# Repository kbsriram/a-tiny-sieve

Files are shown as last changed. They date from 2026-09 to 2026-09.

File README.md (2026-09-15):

# A tiny sieve

Software and hardware for [A Tiny Sieve: Lehmer's math machine in ATtinys](https://hackaday.io/project/206556-a-tiny-sieve-lehmers-math-machine-in-attinys).

A number sieve rejects candidate integers that cannot solve a quadratic
equation, using arithmetic modulo small primes. One ATtiny412 holds one
modulus. They share one open-drain line: any chip that rejects pulls it low, so
the line stays high only when no chip rejected. A Raspberry Pi Pico clocks them
and checks whatever survives.

# Software

One directory per build log, each with its own README:

- [code/01](code/01) — [The sound of sieving](https://hackaday.io/project/206556-a-tiny-sieve-lehmers-math-machine-in-attinys/log/250443-the-sound-of-sieving).
  Three moduli hardcoded, stepped by a button, a buzzer on the shared line.
  Solves `y^2 - 2x^2 = 4001`.
- [code/02](code/02) — [Sieving versus checking](https://hackaday.io/project/206556-a-tiny-sieve-lehmers-math-machine-in-attinys/log/250562-sieving-versus-checking).
  Rings loaded over I2C, clocked at 50 kHz by the Pico's PIO, survivors tested
  on the Pico. Factors 5,283,065,753,709,209.
- [code/04](code/04) — [Qualify the moduli](https://hackaday.io/project/206556-a-tiny-sieve-lehmers-math-machine-in-attinys/log/250711-qualify-the-moduli).
  Testing cards before they ship. Flash a diagnostic image, check the header
  pins from a Pico, then flash the real firmware.
- [code/05](code/05) — Thirty cards on a stripboard backplane. Self-checks over
  I2C before a run, and the REQ-to-VOTE timing measured with all thirty fitted.

Each build pairs an `avr/` half (ATtiny412 firmware in C, avr-gcc) with an
`rpi/` half (Pico host code). The Pico runtime differs per build — build 01 is
CircuitPython, builds 02, 04 and 05 are MicroPython — so check the build's README
before copying files to a board.

# Hardware

- [hardware/modulus](hardware/modulus) is an ATtiny412 on a card that plugs into the sieve backplane. Gerbers, Altium source files and JLCPCB BOM and pick-and-place are available.

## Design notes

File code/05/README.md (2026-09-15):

# 05 - Board bring-up, self-tests

[Build log](https://hackaday.io/project/206556-a-tiny-sieve-lehmers-math-machine-in-attinys/log/250782-the-modulus-chorus-rehearses)

Thirty ATtiny412 cards in a stripboard backplane, checked before a run. The
card firmware gains a CRC-8 checked I2C protocol with a readable status, and a
hand-written interrupt handler that drives VOTE in its first instruction.

## Signals

- **REQ** — Pico output (GP17) to every card (PA6). Each rising edge makes
  every armed card drive VOTE from its ring and advance its phase by one.
- **VOTE** — one wire shared by all thirty cards (PA3) and read by the Pico
  (GP21). No pull-up resistor is fitted: the line is held high by the cards'
  internal pull-ups in parallel, about 1.2 kOhm.
- **I2C** — Pico (GP18 SDA, GP19 SCL) to every card (PA1, PA2) and to an
  SSD1306, at 100 kHz. Cards take no I2C traffic while armed, so REQ is held
  low for every transaction.
- **LED** — PA7 on each card, lit whenever that card is driving VOTE low.

Measured with all thirty cards fitted: 947 ns from a REQ rising edge to VOTE
low, and 1.684 us from the same edge to VOTE settled high.

## ATtiny412 firmware — `avr/`

`src/hal/hal_gpio.c` holds the REQ handler: six assembly instructions with four
registers reserved across the build, and the next phase's port-direction byte
precomputed, so the first instruction executed drives VOTE. `src/task/task_cmd.c`
decodes five commands, each ending in a CRC-8 PEC, and answers every one with a
response code the host reads back. `src/task/task_sieve.c` holds the ring.

Build and flash over serial UPDI, once per card with a distinct I2C address:

    cd avr/src
    make clean flash ADDR=0x10

Set `BASE` and `PORT` for your toolchain and UPDI adapter. Host tests of
`task_cmd.c` and `task_sieve.c` against vectors generated by
`avr/test/ref/model.py`, no hardware needed: `cd avr/test/host && make test`.

## Flashing a batch — `jig/`

`flash_batch.py` runs on the PC and walks a tray of cards one at a time: build
both images, flash the log 4 diagnostic image, run its electrical checks, flash
the log 5 image for the next free address, then check over I2C that the card
answers there and steps its ring. A card that fails any step does not consume
an address.

    python3 jig/flash_batch.py                # batch loop over 30 addresses
    python3 jig/flash_batch.py --verify 0x17  # functional check only

## Pico host — `rpi/` (MicroPython)

`card.py` is one card, `bank.py` all thirty plus the shared REQ and VOTE lines.
`selftest.py` runs the five pre-run checks — roll call, REQ bridge, idle VOTE,
LED walk, and one card at a time against its own ring. `timing.py` loads one
common ring and drives REQ from a hardware PWM, so the scope sees a steady
pattern. `panel.py` drives the OLED, and does nothing if none is fitted.

    cd rpi
    mpremote mount . exec "import selftest; selftest.main(30)"

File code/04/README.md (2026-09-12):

# Card test jig

Tests one ATtiny412 modulus card before it gets the shipping firmware.
Card schematic: [hardware/modulus](../../hardware/modulus).

`test_and_flash.sh` flashes a diagnostic image over UPDI (a UPDI
Friend on H1 pin 6, PA0), then runs the Pico checks. `PORT=` sets the UPDI
serial port; `--batch` loops over a tray of cards.

Diagnostic image: PA6, PA1, PA2, PA3 are inputs with pull-ups; PA7 is a
push-pull output toggling every 1 s.

Checks, in order:

1. All five pins read high. Finds shorts to GND.
2. Drive each of PA6, PA1, PA2, PA3 low in turn; the rest stay high.
   Finds bridges. A pin that will not read low is shorted to VCC.
3. Release all; all read high. Finds opens.
4. Hold pin 3 low for 3 s; no pin follows PA7. Finds a closed JP1
   and any bridge to PA7.

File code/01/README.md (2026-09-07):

# 01 — the sound of sieving

Log: [The sound of sieving](https://hackaday.io/project/206556-a-tiny-sieve-lehmers-math-machine-in-attinys/log/250443-the-sound-of-sieving)

Sieves `y^2 - 2x^2 = 4001`. Three ATtiny412s each hold one modulus, a push
button steps all of them together, and a piezo buzzer sounds on every rejection.

## Wiring

One switch goes to PA1 on every chip, with the internal pull-up on and the other
side to ground, so a press advances every chip's counter by one. PA2 on every
chip is tied to one line, pulled high, with the buzzer across it: a chip that
rejects drives its pin to 0V for about 62 ms, a chip that accepts leaves the pin
as a high-impedance input.

## ATtiny412 firmware — `avr/`

`src/task/task_check.c` holds the accept/reject pattern as a `bool` array, one
entry per residue. Patterns for mod 3, 5, 7 and 11 are all in the file, with one
active and the rest commented out, so you edit and reflash per chip.
`src/task/task_button.c` debounces the press over 3 ticks of the 15.625 ms RTC;
`src/task/task_beep.c` holds the buzzer down for 4 ticks; `src/hal/hal_gpio.c`
drives PA2 with `PORTA.DIRSET`/`DIRCLR`.

    cd avr/src
    make flash            # serial UPDI; set BASE and PORT in the Makefile
    cd ../test/host && make test   # task unit tests, no hardware needed

## Pico — `rpi/` (CircuitPython)

Counts and displays how many candidates have been stepped through. Copy
`code.py` and `lib/` to the CIRCUITPY drive. `lib/button.py` debounces the
switch with a 47 ms settle window; `lib/count_display.py` drives a 128x64
SSD1306 OLED over I2C.

`diag.py` prints how long the switch stayed at each level. Copy it over
`code.py` to measure the contact bounce that made the count jump by more than
one per press.

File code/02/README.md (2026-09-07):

# 02 — sieving versus checking

Log: [Sieving versus checking](https://hackaday.io/project/206556-a-tiny-sieve-lehmers-math-machine-in-attinys/log/250562-sieving-versus-checking)

Factors 5,283,065,753,709,209 by searching for `a^2 + 7*(4k)^2 = N`. Three
ATtiny412s reject candidate values of `k`; a Pico steps them and tests what
survives for a perfect square.

## Signals

- **REQ** — Pico output (GP14) to every ATtiny (PA6). Each rising edge makes
  every chip read one bit of its ring and advance its counter by one.
- **VOTE** — one wire shared by all three chips (PA7) and read by the Pico
  (GP15). A chip that rejects drives it low; a chip that accepts leaves the pin
  as a high-impedance input. So VOTE is high only if no chip rejected.
- **I2C** — Pico (GP16 SDA, GP17 SCL) to each chip (PA1, PA2), used before the
  run to load each chip's modulus and ring.

A chip's *ring* is its modulus `p` plus 16 bytes = 128 bits, one bit per
residue: bit `r` is 1 if `N - 7*(4r)^2` is a quadratic residue mod `p`, meaning
candidates with `k = r mod p` can still be solutions. 128 bits caps the modulus
at 128.

## ATtiny412 firmware — `avr/`

`src/task/task_sieve.c` is the whole rejecter: modulus, ring, phase counter, and
three I2C commands — `0x01` set ring, `0x02` reset and disarm, `0x03` arm.
`src/hal/hal_gpio.c` does the open-drain VOTE with `PORTA.DIRSET`/`DIRCLR`.
`main.c` never sleeps while armed, because waking from sleep costs microseconds
that would push the REQ-to-VOTE delay past the 20 us step period.

Build and flash over serial UPDI, once per chip with a distinct I2C address:

    cd avr/src
    make ADDR=0x20 flash
    make ADDR=0x21 flash
    make ADDR=0x22 flash

Set `BASE` and `PORT` in `src/Makefile` for your toolchain and UPDI adapter.
Host-side unit tests of `task_sieve.c` (no hardware needed): `cd avr/test/host
&& make test`.

## Pico host — `rpi/` (MicroPython)

`sieve_runner.py` holds the PIO program: it drives REQ at 50 kHz (10 us high,
10 us low), samples VOTE near the end of the low phase, and pushes a 64-bit
candidate index into the FIFO only when VOTE was high. `sieve.py` is the I2C
driver for one chip. `check_16.py` builds the rings from quadratic residues,
verifies the first 10,000 candidates against a Python oracle, then runs to
completion and recovers the factors with `gcd`.

Run anything with the directory mounted, no copying to flash:

    cd rpi
    mpremote mount . run check_16.py

## Tests

All four need the hardware attached, and are run the same way.

- `test_functional.py` — one chip, degenerate rings (all-accept, all-reject,
  alternating, single bit); the other chips left disarmed.
- `test_survivors.py` — arms 1, then 2, then 3 chips and re-checks survivors,
  confirming disarmed chips never pull VOTE low.
- `test_differential.py` — random rings across moduli up to 127, checking the
  ring wraps correctly at byte boundaries.
- `test_overflow.py` — the PIO's 64-bit candidate counter across 0xFFFFFFFF.

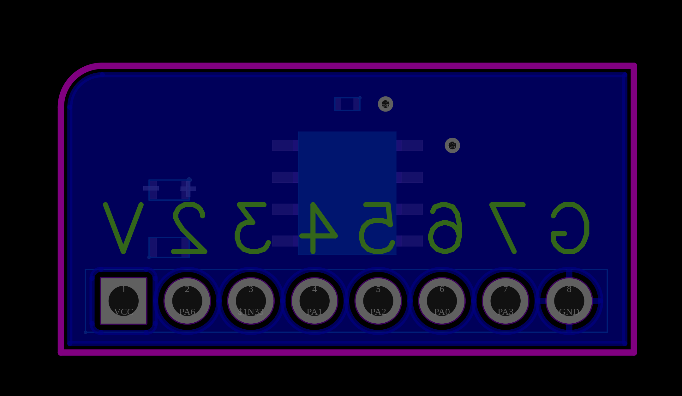
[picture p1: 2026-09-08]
hardware/modulus/pcb_back.png

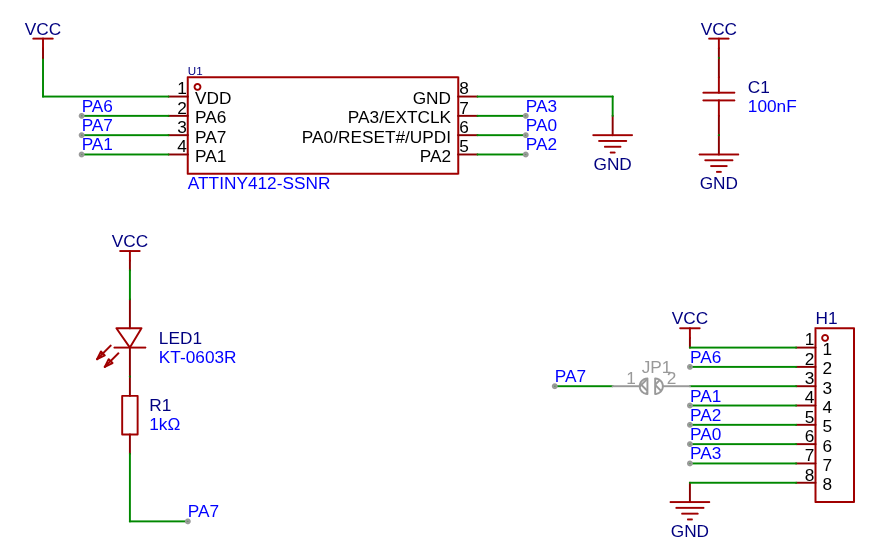
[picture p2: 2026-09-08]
hardware/modulus/schematic.png

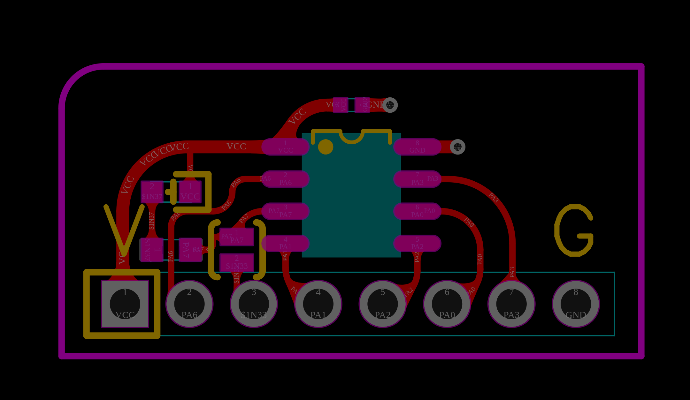
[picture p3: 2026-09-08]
hardware/modulus/pcb_front.png

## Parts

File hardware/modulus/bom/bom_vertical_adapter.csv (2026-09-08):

No. | Quantity | Comment | Designator | Footprint | Value | Manufacturer Part | Manufacturer | Supplier Part | Supplier
1 | 1 | 100nF | C1 | C0402 | 100nF | CL05B104KB54PNC | SAMSUNG(三星) | C307331 | LCSC
2 | 1 | HDR-F_2.54_1x8P | H1 | HDR-TH_8P-P2.54-V-F-1
3 | 1 | KT-0603R | LED1 | LED-SMD_L1.6-W0.8-R-RD |  | KT-0603R | KENTO | C2286 | LCSC
4 | 1 | 1kΩ | R1 | R0603 | 1kΩ | 0603WAF1001T5E | UNI-ROYAL(厚声) | C21190 | LCSC
5 | 1 | ATTINY412-SSNR | U1 | SOIC-8_L4.9-W3.9-P1.27-LS6.0-BL |  | ATTINY412-SSNR | MICROCHIP(美国微芯) | C1337190 | LCSC

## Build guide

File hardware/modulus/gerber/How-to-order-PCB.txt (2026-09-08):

How to Order PCB

Please refer to:
https://prodocs.easyeda.com/en/pcb/order-order-pcb/index.html

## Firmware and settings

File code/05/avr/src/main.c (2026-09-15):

#include <avr/interrupt.h>
#include <stdint.h>

#include "hal/hal_gpio.h"
#include "hal/hal_system.h"
#include "hal/hal_twi.h"
#include "task/task_cmd.h"

// Apply pin-level effects of the command task_cmd already decoded.
static void apply_command(void) {
  switch (task_cmd_accepted_op()) {
    case TASK_CMD_OP_SET_RING:
      // SET_RING disarms (clearing the LED); restore the LED state after.
      hal_gpio_disarm();
      hal_gpio_set_ring();
      hal_gpio_led(task_cmd_led());
      break;
    case TASK_CMD_OP_RESET:
      hal_gpio_disarm();
      break;
    case TASK_CMD_OP_ARM:
      hal_gpio_arm(task_cmd_accepted_phase());
      break;
    case TASK_CMD_OP_LED:
      hal_gpio_led(task_cmd_led());
      break;
    default:
      break;
  }
}

int main(void) {
  hal_system_init();
  // Pins first: VOTE and the LED stay high-impedance until a command or a REQ
  // edge changes them.
  hal_gpio_init();

  // Same address twice: task_cmd seeds every CRC with it, hal_twi matches it.
  task_cmd_init(I2C_ADDR);
  hal_twi_init(I2C_ADDR);

  sei();

  // Never sleeps, never disables interrupts: every REQ edge reaches the handler
  // in the cycle count hal_gpio.c guarantees.
  while (1) {
    if (hal_twi_take_command()) {
      apply_command();
    }
  }
}

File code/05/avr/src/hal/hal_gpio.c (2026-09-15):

#include "hal_gpio.h"

#include <avr/cpufunc.h>
#include <avr/interrupt.h>
#include <avr/io.h>

#include "task/task_sieve.h"

// DIR=1 drives low; OUT stays 0. 0x88 sinks VOTE and lights the LED.
#define VOTE_LOW_DIR (PIN3_bm | PIN7_bm)

// VPORTA.DIR value per phase. One spare entry so the ISR's pointer stays
// in-bounds after the last phase.
static uint8_t s_dir[TASK_SIEVE_MODULUS_MAX + 1];

// Owned by the ISR, reserved in the Makefile via -ffixed.
register uint8_t s_next_dir __asm__("r2");      // DIR value for the next edge
register const uint8_t *s_next __asm__("r26");  // &s_dir[next phase]
register uint8_t s_wrap_lo __asm__("r4");       // low byte of &s_dir[modulus]

// REQ rising edge on PA6. ISR_NAKED because avr-gcc's prologue would delay the
// OUT that drives VOTE. No SREG save: no instruction here writes a flag, which
// is also why CPSE is used instead of CP.
//
// 6 cycles from the edge to PA3 sinking, 16 to the end of RETI, the same at
// every phase. Measured: 947 ns and 1.684 us with 30 cards fitted.
//
// SBI clears any set INTFLAGS bit, so no other PA pin may have an edge sense.
// Errata DS80000933D: a store >=64 then one <64 loses the second; OUT avoids
// ST.
// cppcheck-suppress unusedFunction  ; the vector table calls it.
ISR(PORTA_PORT_vect, ISR_NAKED) {
  __asm__ volatile(
      "out  %[dir], r2"
      "\n\t"  // drive VOTE and the LED
      "sbi  %[flags], 6"
      "\n\t"  // clear the PA6 interrupt flag
      "cpse r26, r4"
      "\n\t"  // reached &s_dir[modulus]?
      "rjmp .+2"
      "\n\t"  // no: keep the pointer
      "ldi  r26, lo8(%[tbl])"
      "\n\t"  // yes: phase wraps to 0
      "ld   r2, X+"
      "\n\t"  // next edge's value, advance the phase
      "reti"
      "\n\t"
      :
      : [dir] "I"(_SFR_IO_ADDR(VPORTA.DIR)),
        [flags] "I"(_SFR_IO_ADDR(VPORTA.INTFLAGS)), [tbl] "i"(&s_dir[0]));
}

// Phase 0, VOTE released. Call only with the PA6 edge disabled. s_next points
// one ahead of s_next_dir, so hal_gpio_phase() returns 0.
static void rewind_phase(void) {
  s_next_dir = 0;
  s_next = &s_dir[1];
  s_wrap_lo = (uint8_t)(uint16_t)&s_dir[1];
}

void hal_gpio_init(void) {
  PORTA.OUT = 0;  // OUT stays 0 forever; DIR drives low or releases.
  PORTA.DIR = 0;

  // An input buffer with no reader only draws current. PA1 and PA2 stay off
  // until hal_twi_init() re-enables them. PA6 with no edge sense is disarmed.
  PORTA.PIN0CTRL = PORT_ISC_INPUT_DISABLE_gc;
  PORTA.PIN1CTRL = PORT_ISC_INPUT_DISABLE_gc;
  PORTA.PIN2CTRL = PORT_ISC_INPUT_DISABLE_gc;
  PORTA.PIN3CTRL = PORT_PULLUPEN_bm | PORT_ISC_INPUT_DISABLE_gc;
  PORTA.PIN6CTRL = PORT_PULLUPEN_bm;
  PORTA.PIN7CTRL = PORT_ISC_INPUT_DISABLE_gc;

  PORTA.INTFLAGS = 0xFF;  // Discard flags set during pin config.
  rewind_phase();
}

void hal_gpio_set_ring(void) {
  // SET_RING disarms, so no REQ edge can read a half-rewritten table.
  const uint8_t modulus = task_sieve_modulus();
  for (uint8_t phase = 0; phase < modulus; phase++) {
    s_dir[phase] = task_sieve_release(phase) ? 0 : VOTE_LOW_DIR;
  }
}

void hal_gpio_arm(uint8_t phase) {
  const uint8_t modulus = task_sieve_modulus();

  const uint8_t sreg = SREG;
  cli();  // Stop a mid-update edge mixing old and new phase registers.

  s_next_dir = s_dir[phase];
  s_next = &s_dir[phase + 1];  // One ahead of the value in r2.
  s_wrap_lo = (uint8_t)(uint16_t)&s_dir[modulus];

  PORTA.INTFLAGS = PIN6_bm;  // Discard edges seen while disarmed.
  PORTA.PIN6CTRL = PORT_PULLUPEN_bm | PORT_ISC_RISING_gc;

  SREG = sreg;
}

void hal_gpio_disarm(void) {
  const uint8_t sreg = SREG;
  cli();  // Stop an edge re-driving VOTE after the release below.

  PORTA.PIN6CTRL = PORT_PULLUPEN_bm;
  PORTA.INTFLAGS = PIN6_bm;
  // Errata DS80000933D: a store to INTFLAGS (>= 64) immediately followed by
  // one to VPORTA.DIR (< 64) loses the second.
  _NOP();
  VPORTA.DIR = 0;

  rewind_phase();
  SREG = sreg;
}

void hal_gpio_led(bool on) {
  // Disarmed: DIR is 0 and the ISR cannot run, so no guard is needed.
  VPORTA.DIR = on ? PIN7_bm : 0;
}

uint8_t hal_gpio_phase(void) {
  return (uint8_t)(s_next - &s_dir[0]) - 1;  // s_next is one phase ahead.
}

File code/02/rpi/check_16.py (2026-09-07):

"""Factors 16-digit M = 5283065753709209 = x^2 + 7y^2.
Prunes y = 4k (since M = 1 mod 8). Steps k at 50 kHz across
moduli [5, 11, 23], verifying (M - 7*(4k)^2) mod p in squares(p).
Survivors are tested for exact squares to find Lehmer's factors.
"""

import time
from machine import I2C, Pin
import pins
import ssd1306
from sieve import Sieve
from sieve_runner import SieveRunner

# Modes to execute (flip as needed)
RUN_VERIFY = True  # Mode A: 10,000 candidate lint check
RUN_FULL = True  # Mode B: Full streaming hunt to completion

M = 5283065753709209
MODULI = [5, 11, 23]
DISP_ADDR = 0x3C  # SSD1306 OLED shares the ATtiny I2C bus
MAX_K = 6868058  # y = 4k <= isqrt(M // 7) = 27472234

# Fast modulo 64 quadratic residue filter
SQ64 = bytearray(64)
for i in range(64):
    SQ64[(i * i) & 63] = 1


def isqrt(n):
    """Integer square root via Newton's method."""
    if n < 2:
        return n
    x = n
    y = (x + 1) // 2
    while y < x:
        x = y
        y = (x + n // x) // 2
    return x


def check_square(n):
    """Returns (root, True) if n is an exact integer square, else (0, False)."""
    # First run another fast modulus check to reject candidates quickly
    if n < 0 or not SQ64[n & 63]:
        return 0, False
    # Calculate the actual square root now
    r = isqrt(n)
    return r, (r * r == n)


def gcd(a, b):
    while b:
        a, b = b, a % b
    return a


def make_ring(p, m_val=M):
    """Builds 16-byte truth table for modulus p with candidate k where y = 4k."""
    squares = {(r * r) % p for r in range(p)}
    bits = bytearray(16)
    expected_phases = []
    for k in range(p):
        y = (4 * k) % p
        if (m_val - 7 * y * y) % p in squares:
            bits[k // 8] |= 1 << (k % 8)
            expected_phases.append(k)
    return bits, expected_phases


def make_display(i2c, devices):
    """Returns a 128x64 SSD1306 if one answered the bus scan, else None."""
    if DISP_ADDR not in devices:
        return None
    oled = ssd1306.SSD1306_I2C(128, 64, i2c, addr=DISP_ADDR)
    oled.fill(0)
    oled.show()
    return oled


def show(oled, *lines):
    """Redraws the panel, one 8x8 text line per argument (6 lines max).

    Costs ~25 ms: 1024 framebuffer bytes at 400 kHz. Call it sparingly.
    """
    if oled is None:
        return
    oled.fill(0)
    for row, line in enumerate(lines):
        oled.text(line, 0, row * 10)
    oled.show()


def setup_hardware():
    i2c = I2C(0, scl=Pin(pins.PIN_SCL), sda=Pin(pins.PIN_SDA), freq=400000)
    req = Pin(pins.PIN_REQ, Pin.OUT)
    vote = Pin(pins.PIN_VOTE, Pin.IN, Pin.PULL_UP)

    # Dynamically discover the number of connected tinys with a scan on the i2c bus.
    # 0x3C is a display, which we skip.
    found = i2c.scan()
    oled = make_display(i2c, found)
    devices = [d for d in found if d != DISP_ADDR]
    if len(devices) < len(MODULI):
        raise RuntimeError(
            f"Found {len(devices)} ATtinys ({[hex(d) for d in devices]}), need {len(MODULI)}"
        )

    sieves = [Sieve(i2c, addr) for addr in devices[: len(MODULI)]]
    runner = SieveRunner(req, vote, sieves=sieves, sm_id=0, freq=5000000)

    configs = []
    oracle_accepts = {}
    for p in MODULI:
        bits, exp_phases = make_ring(p)
        configs.append((p, bits))
        oracle_accepts[p] = set(exp_phases)

    return runner, configs, oracle_accepts, oled


def verify_sample(runner, configs, oracle_accepts, oled=None, num_candidates=10000):
    """Mode A: Verifies hardware survivors strictly match mathematical expectation."""
    print(f"\n--- Mode A: Lint & Verification (first {num_candidates} candidates) ---")
    expected = [
        k
        for k in range(num_candidates)
        if all((k % p) in oracle_accepts[p] for p in MODULI)
    ]
    print(
        f"Expecting {len(expected)} survivors ({100.0 * len(expected) / num_candidates:.2f}% pass rate)..."
    )

    show(oled, "MODE A", "verifying", f"{num_candidates:,} cands")
    runner.configure_array(configs, start_candidate=0)
    t0 = time.ticks_us()
    hw_survivors = [runner.next_survivor() for _ in range(len(expected))]
    elapsed_us = time.ticks_diff(time.ticks_us(), t0)
    runner.pause()

    passed = hw_survivors == expected
    rate_khz = (num_candidates * 1000) / elapsed_us if elapsed_us > 0 else 0

    show(
        oled,
        "MODE A",
        "PASS" if passed else "FAIL",
        f"{num_candidates:,} cands",
        f"{rate_khz:.1f} kHz",
    )
    if passed:
        print(
            f"PASS: 100% agreement over {num_candidates} candidates ({elapsed_us/1000:.1f} ms, {rate_khz:.2f} kHz)."
        )
    else:
        print("FAIL: Discrepancy detected between hardware and expected survivors.")
        for i, (exp, got) in enumerate(zip(expected, hw_survivors)):
            if exp != got:
                print(f"  First mismatch at survivor #{i}: expected {exp}, got {got}")
                break
    return passed
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

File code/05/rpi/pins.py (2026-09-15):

"""Raspberry Pi Pico GPIO numbers for the stripboard backplane.

REQ, VOTE, SDA and SCL run to all 30 card slots in parallel; the SSD1306 sits on
the same I2C bus. The jig socket has its own numbers in jig_pins.py.

Strips run horizontally, so one strip is one row. The Pico's right-hand column of pins stands on rows y=2.3 to 3.0,
the same rows as the first card slot, with no trace cut between them:

    signal   strip   Pico pin   GP
    vote      2.4       27      21
    updi      2.5       26      20
    SCL       2.6       25      19
    SDA       2.7       24      18
    req       2.9       22      17

Pin to GP numbering: the Pico datasheet pinout,
https://datasheets.raspberrypi.com/pico/pico-datasheet.pdf
"""

PIN_REQ = 17  # Pico pin 22. Driven by the Pico, read by every card's PA6.
PIN_VOTE = 21  # Pico pin 27. Open drain, 30 cards' PA3 in parallel.
PIN_SDA = 18  # Pico pin 24.
PIN_SCL = 19  # Pico pin 25.
PIN_UPDI = 20  # Pico pin 26. Card flashing only; nothing in 05/rpi drives it.

# GP18 and GP19 are the I2C1 pins on the RP2040.
I2C_ID = 1
I2C_HZ = 100_000

# One 1024-byte SSD1306 frame is 92 ms at 100 kHz, past MicroPython's 50 ms
# rp2 default. A full display init measured 114 ms.
I2C_TIMEOUT_US = 200_000

# The card firmware is specified at 100 kHz, so the OLED runs at that speed too.
OLED_ADDR = 0x3C
OLED_WIDTH = 128
OLED_HEIGHT = 64

# VOTE is read with the RP2040 pull-up off. No resistor is fitted: the line is
# pulled up by the 30 cards' internal pull-ups in parallel, about 1.2 kOhm.
VOTE_PULLUP = False

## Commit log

2026-09-05 add I2C and RPI for debugging attiny code
2026-09-05 add twi peripheral/array set/reset/arm commands
    [hal_gpio.c, hal_twi.c, main.c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]
2026-09-08 modulus design files
    [Drill_PTH_Through.DRL, Drill_PTH_Through_Via.DRL, Gerber_BoardOutlineLayer.GKO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]
2026-09-08 add README and images for schematic and layout.
2026-09-14 Set clock, fuses, and reset-cause snapshot
    - BODCFG 2.6 V, OSCCFG 20 MHz, CLK_PER 10 MHz
    - Snapshot RSTCTRL.RSTFR at boot, report via LED pulses
    - Replace RTC blink with 1 ms delay loop
    [main.c]
2026-09-14 Add ring, phase, and arm logic with vectors
2026-09-14 Add CRC-8 PEC and I2C command decoder
2026-09-15 Add REQ interrupt handler, pins, and VOTE output
    - 11-cycle assembly handler, four reserved registers
    - Phase lives in the handler, not task_sieve
    - Pico REQ walk passes on hardware
2026-09-15 05: I2C client with response-code protocol
2026-09-15 05: Pico host self-test and batch card flasher
    - Five pre-run checks; 10 cards pass on hardware.
    - flash_batch.py tests, flashes and addresses cards.
    - OLED needs 200 ms I2C timeout, not 50.
